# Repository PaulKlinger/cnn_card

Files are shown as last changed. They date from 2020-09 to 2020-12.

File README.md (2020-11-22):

# CNN card

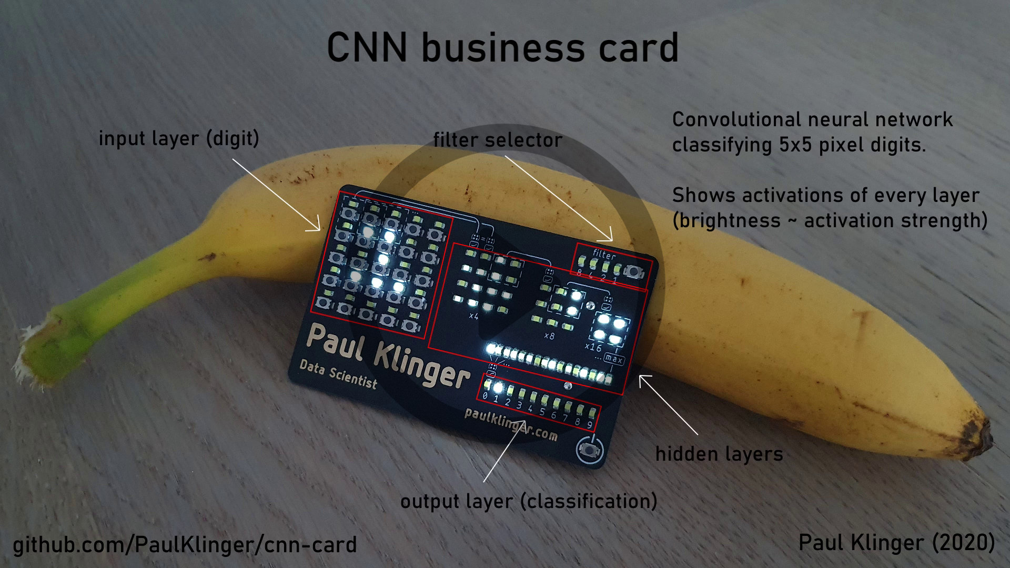
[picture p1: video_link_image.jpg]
(https://youtu.be/wtxGkK6LNEg "Project video")


Business card that runs a convolutional neural network to classify 5x5 pixel digits and shows the internal activations for all layers.

## Model
Training data / notebook for the cnn [here](https://github.com/PaulKlinger/cnn_card/blob/master/cnn).

The model consists of 3 convolutional layers (4, 8, 16 filters) and a dense layer at the output. The training data is manually generated (whatever I could come up with) + some augmentation (shifting & random pixel flips). The number of parameters is quite large compared to the number of training samples so this is probably mostly overfitting (although that might be the wrong word here, as I don't think there are many more possible samples I could have included).

## Code
The embedded code is in the [cnn_card_embedded_code.X](https://github.com/PaulKlinger/cnn_card/tree/master/cnn_card_embedded_code.X) folder (MplabX project).

The leds and buttons are driven/scanned using multiplexing, via two shift registers. The main challenge with the code was making this fast and consistent enough to allow PWM control of the brightness.

The model weights are exported to c code in [train.ipynb](https://github.com/PaulKlinger/cnn_card/blob/master/cnn/train.ipynb) and copied to [model_weights.c](https://github.com/PaulKlinger/cnn_card/blob/master/cnn_card_embedded_code.X/model_weights.c).

The aux_code directory contains some auxiliary notebooks: One to generate the startup animation (concentric pulse) and one to calculate the gamma correction table for the leds.

## Electronics
PCB design (gerbers and Eagle/Fusion sources) in the [pcb folder](https://github.com/PaulKlinger/cnn_card/tree/master/pcb).

Schematic [here](https://github.com/PaulKlinger/cnn_card/blob/master/pcb/schematic.pdf).

List of components (bill of materials) [here](https://github.com/PaulKlinger/cnn_card/blob/master/pcb/bom.csv).

I had the PCB made by elecrow.com, 1mm thickness, ENIG, matte black soldermask. I also ordered a stencil from them and used hot air & paste to solder everything (except for the battery/holder, that was done manually).

For testing I used the coin cell battery holder listed in the BOM, and then replaced it with a CR2032 with tabs soldered on (to reduce the thickness a bit).

The battery should last basically forever (decades) in standby (0.14 µA) and > 10 hours during use (it draws less than 10mA at maximum (max brightness on all leds) but probably closer to 2-3mA in normal use). After 2min of no input it automatically goes into standby mode.

I found that using white LEDs works best (in terms of max brightness), even though the forward voltage looks like it should be too high for the CR2032. At the low currents here (<0.1 mA averaged per led, <1mA momentarily due to the multiplexing) the forward voltage isn't a problem and white LEDs are just much more efficient. Also, the phosphor means that the light is more diffuse which looks nicer.

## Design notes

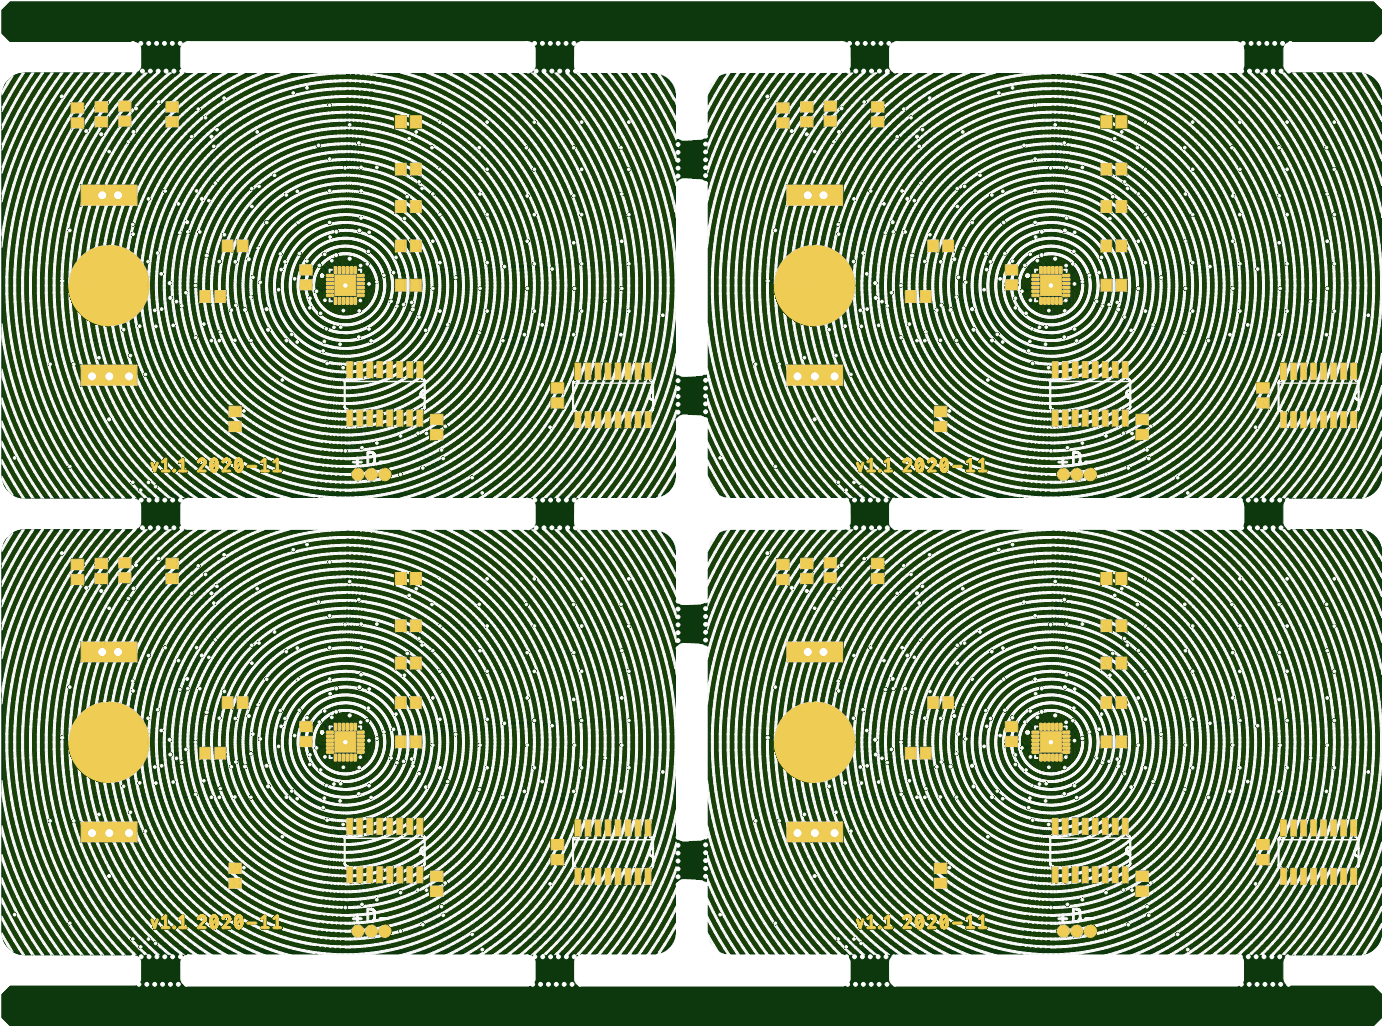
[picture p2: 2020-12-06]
pcb/panel_2x2/panel_2x2_Combined_Bottom.png

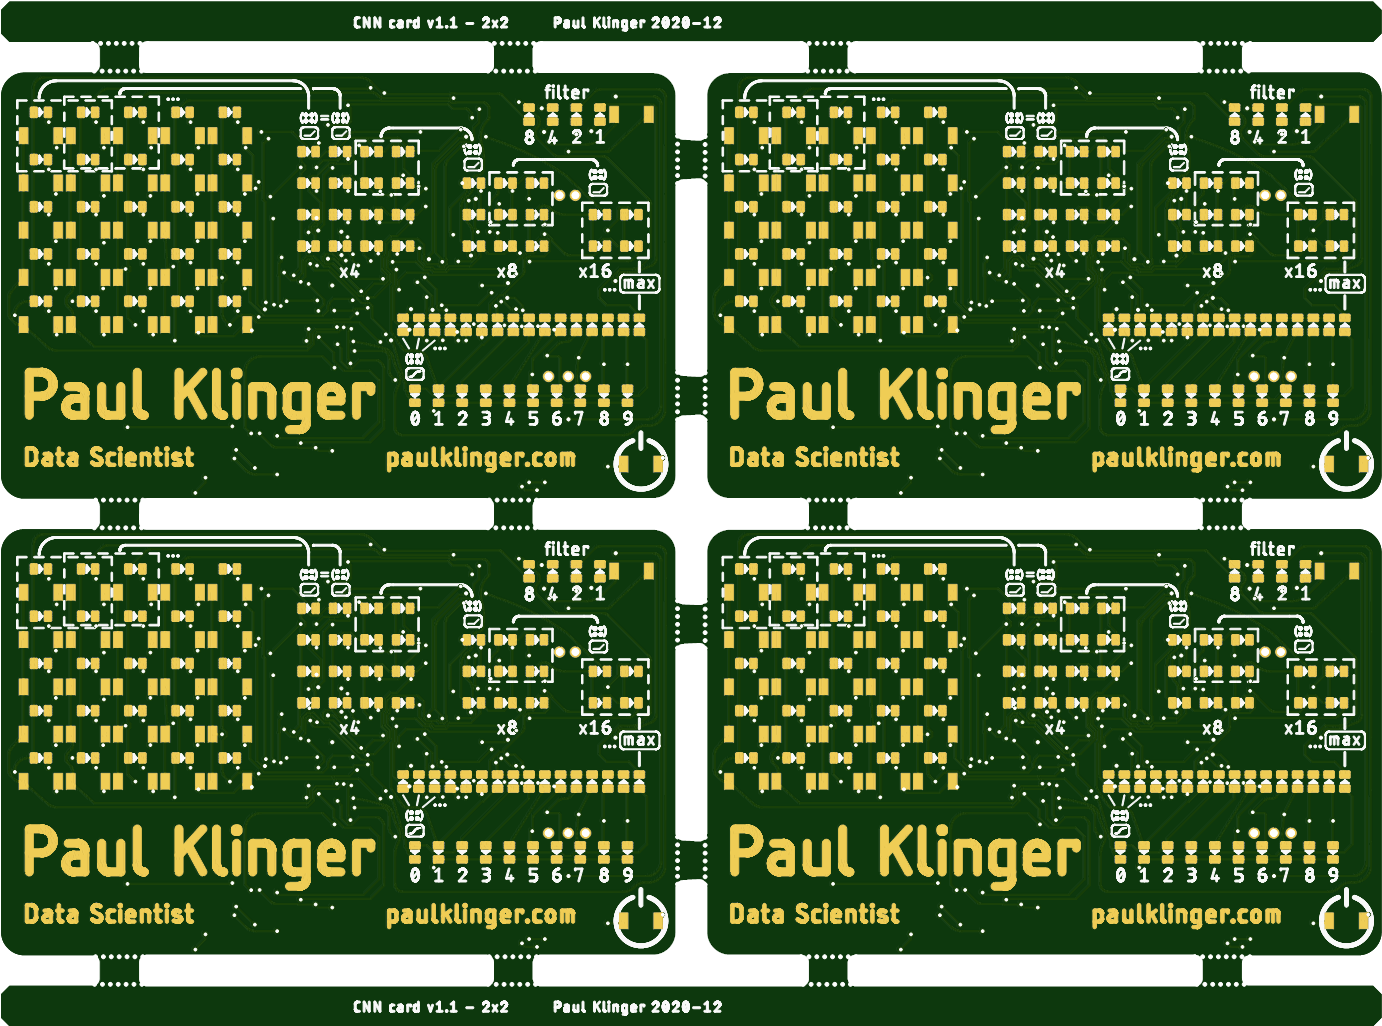
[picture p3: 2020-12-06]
pcb/panel_2x2/panel_2x2_Combined_Top.png

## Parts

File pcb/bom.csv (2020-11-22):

Qty | Value | Device | Package | Description | Parts
3 | 10uf |  | 0805 | ceramic capacitor | C1, C2, C3
9 | 220 Ω |  | 0805 | resistor | R1, R2, R3, R4, R5, R6, R7, R8, R9
3 | 2.2 kΩ |  | 0805 | resistor | R10, R11, R12
1 |  | SMTU2032-LF |  | CR2032 coin cell battery holder | U$1
2 |  | 74HC595D | SO16 | 8-bit SHIFT REGISTER, output latch | IC1, IC2
1 |  | ATTINY3217-MFR | QFN50P400X400X90-25N | Attiny3217 microcontroller | U3
27 | B3U-1000P-2P-SMD | SMD-BUTTON(2P-3.0X2.5X1.2+0.4MM)-B3U-1000P-2P-SMD | SW2-2.6-3.0X2.5X1.2+0.4MM | smd pushbutton | FILTER_SW, PWR_SW, SW1, SW2, SW3, SW4, SW5, SW6, SW7, SW8, SW9, SW10, SW11, SW12, SW13, SW14, SW15, SW16, SW17, SW18, SW19, SW20, SW21, SW22, SW23, SW24, SW25
84 |  | SMD-LED-CLEAR-WHITE(0805) | LED-0805 | white 0805 SMD led | D1, D2, D3, D4, D5, D6, D7, D8, D9, D10, D11, D12, D13, D14, D15, D16, D17, D18, D19, D20, D21, D22, D23, D24, D25, D26, D27, D28, D29, D30, D31, D32, D33, D34, D35, D36, D37, D38, D39, D40, D41, D42, D43, D44, D45, D46, D47, D48, D49, D50, D51, D52, D53, D54, D55, D56, D57, D61, D62, D63, D64, D65, D66, D67, D68, D69, D71, D72, D73, D74, D75, D76, D77, D78, D79, D81, D82, D83, D84, D85, D86, D87, D88, D89

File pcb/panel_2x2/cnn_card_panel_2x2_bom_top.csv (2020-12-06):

ID | Name | Designator | Footprint | Quantity | Manufacturer Part | Manufacturer | Supplier | Supplier Part
1 | C34499 | D34_00_00,D1_00_00,D2_00_00,D3_00_00,D4_00_00,D5_00_00,D6_00_00,D7_00_00,D8_00_00,D9_00_00,D10_00_00,D11_00_00,D12_00_00,D13_00_00,D14_00_00,D15_00_00,D16_00_00,D17_00_00,D18_00_00,D19_00_00,D20_00_00,D21_00_00,D22_00_00,D23_00_00,D24_00_00,D25_00_00,D26_00_00,D27_00_00,D28_00_00,D29_00_00,D30_00_00,D31_00_00,D32_00_00,D33_00_00,D35_00_00,D36_00_00,D37_00_00,D38_00_00,D39_00_00,D40_00_00,D41_00_00,D42_00_00,D43_00_00,D44_00_00,D45_00_00,D46_00_00,D47_00_00,D48_00_00,D49_00_00,D50_00_00,D51_00_00,D52_00_00,D53_00_00,D54_00_00,D61_00_00,D62_00_00,D63_00_00,D64_00_00,D65_00_00,D66_00_00,D67_00_00,D68_00_00,D69_00_00,D71_00_00,D72_00_00,D73_00_00,D74_00_00,D75_00_00,D76_00_00,D77_00_00,D78_00_00,D79_00_00,D81_00_00,D82_00_00,D83_00_00,D84_00_00,D85_00_00,D86_00_00,D87_00_00,D88_00_00,D89_00_00,D55_00_00,D56_00_00,D57_00_00,D34_00_01,D1_00_01,D2_00_01,D3_00_01,D4_00_01,D5_00_01,D6_00_01,D7_00_01,D8_00_01,D9_00_01,D10_00_01,D11_00_01,D12_00_01,D13_00_01,D14_00_01,D15_00_01,D16_00_01,D17_00_01,D18_00_01,D19_00_01,D20_00_01,D21_00_01,D22_00_01,D23_00_01,D24_00_01,D25_00_01,D26_00_01,D27_00_01,D28_00_01,D29_00_01,D30_00_01,D31_00_01,D32_00_01,D33_00_01,D35_00_01,D36_00_01,D37_00_01,D38_00_01,D39_00_01,D40_00_01,D41_00_01,D42_00_01,D43_00_01,D44_00_01,D45_00_01,D46_00_01,D47_00_01,D48_00_01,D49_00_01,D50_00_01,D51_00_01,D52_00_01,D53_00_01,D54_00_01,D61_00_01,D62_00_01,D63_00_01,D64_00_01,D65_00_01,D66_00_01,D67_00_01,D68_00_01,D69_00_01,D71_00_01,D72_00_01,D73_00_01,D74_00_01,D75_00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 | LED-0805 | 336 | whiteLEDSMD | KENTO | LCSC | C34499
2 | TS342A2P-WZ | SW1_00_00,SW2_00_00,SW3_00_00,SW4_00_00,SW5_00_00,SW6_00_00,SW7_00_00,SW8_00_00,SW9_00_00,SW10_00_00,SW11_00_00,SW12_00_00,SW13_00_00,SW14_00_00,SW15_00_00,SW16_00_00,SW17_00_00,SW18_00_00,SW19_00_00,SW20_00_00,SW21_00_00,SW22_00_00,SW23_00_00,SW24_00_00,SW25_00_00,PWR_SW_00_00,FILTER_SW_00_00,SW1_00_01,SW2_00_01,SW3_00_01,SW4_00_01,SW5_00_01,SW6_00_01,SW7_00_01,SW8_00_01,SW9_00_01,SW10_00_01,SW11_00_01,SW12_00_01,SW13_00_01,SW14_00_01,SW15_00_01,SW16_00_01,SW17_00_01,SW18_00_01,SW19_00_01,SW20_00_01,SW21_00_01,SW22_00_01,SW23_00_01,SW24_00_01,SW25_00_01,PWR_SW_00_01,FILTER_SW_00_01,SW1_01_00,SW2_01_00,SW3_01_00,SW4_01_00,SW5_01_00,SW6_01_00,SW7_01_00,SW8_01_00,SW9_01_00,SW10_01_00,SW11_01_00,SW12_01_00,SW13_01_00,SW14_01_00,SW15_01_00,SW16_01_00,SW17_01_00,SW18_01_00,SW19_01_00,SW20_01_00,SW21_01_00,SW22_01_00,SW23_01_00,SW24_01_00,SW25_01_00,PWR_SW_01_00,FILTER_SW_01_00,SW1_01_01,SW2_01_01,SW3_01_01,SW4_01_01,SW5_01_01,SW6_01_01,SW7_01_01,SW8_01_01,SW9_01_01,SW10_01_01,SW11_01_01,SW12_01_01,SW13_01_01,SW14_01_01,SW15_01_01,SW16_01_01,SW17_01_01,SW18_01_01,SW19_01_01,SW20_01_01,SW21_01_01,SW22_01_01,SW23_01_01,SW24_01_01,SW25_01_01,PWR_SW_01_01,FILTER_SW_01_01 | SW-SMD_L4.0-W2.9-LS5.0 | 108 | TS342A2P-WZ | SHOU HAN | LCSC | C557591

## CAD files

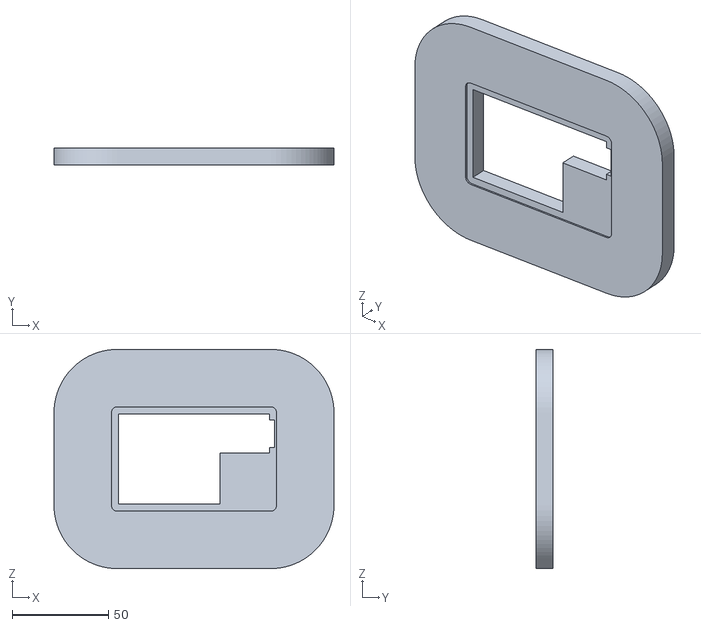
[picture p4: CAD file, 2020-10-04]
pcb/paste_holder_top.stl
145.6 x 8.90 x 114.0

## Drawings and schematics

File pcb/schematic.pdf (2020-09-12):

## VCC

1

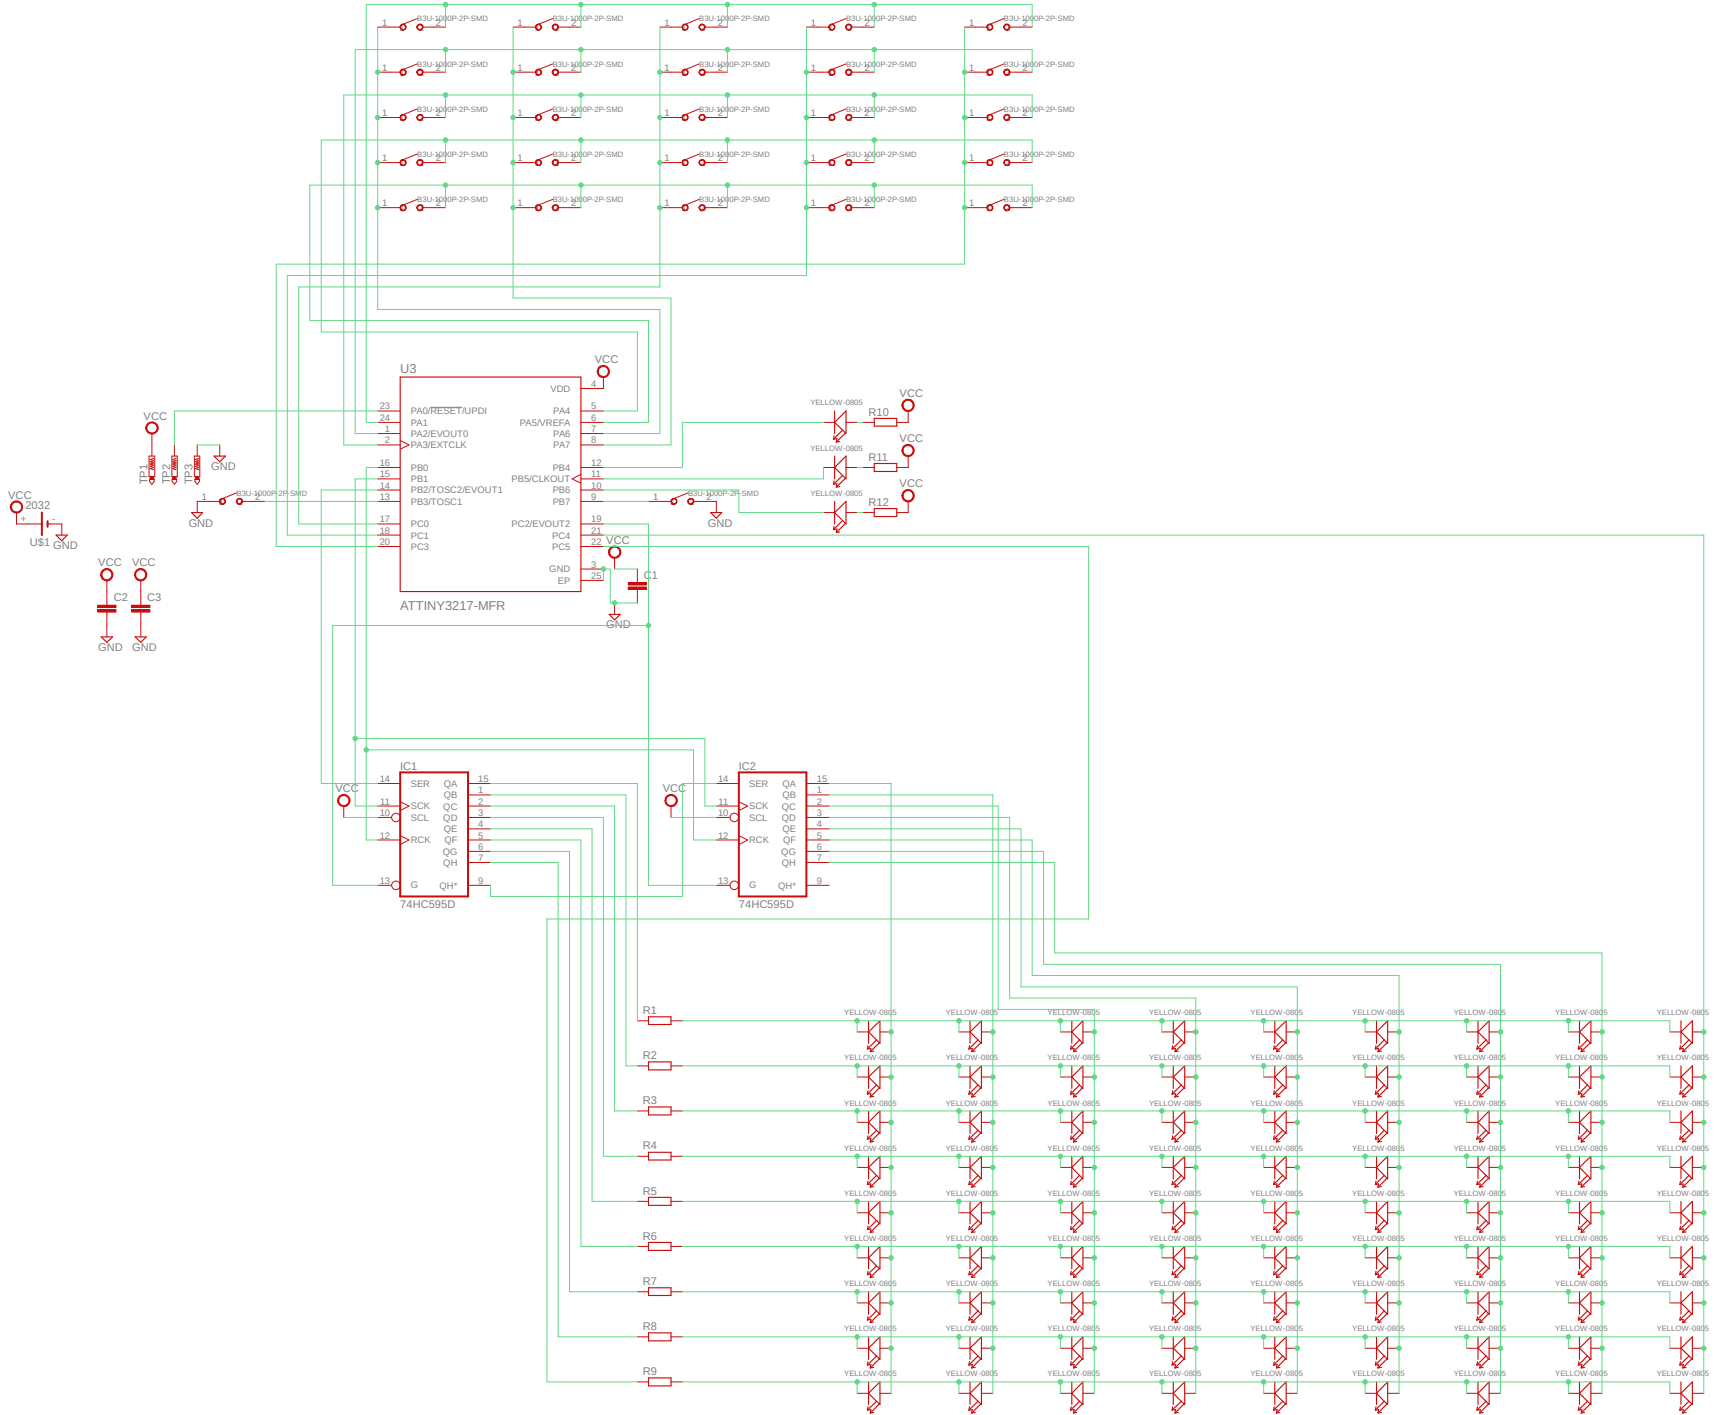
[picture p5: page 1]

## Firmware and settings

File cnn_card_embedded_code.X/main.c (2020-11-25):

#include "config.h"

#include <avr/io.h>
#include <util/delay.h>
#include <avr/sleep.h>
#include <avr/interrupt.h>

#include "model/model.h"
#include "util/led_control.h"
#include "util/buttons.h"
#include "util/sleep.h"
#include "fun/startup_anim.h"
#include "fun/gol.h"


FUSES = 
{
	.APPEND = 0,
	.BODCFG = ACTIVE_DIS_gc | LVL_BODLEVEL0_gc | SAMPFREQ_1KHZ_gc | SLEEP_DIS_gc,
	.BOOTEND = 0,
	.OSCCFG = FREQSEL_20MHZ_gc,
	.SYSCFG0 = CRCSRC_NOCRC_gc | RSTPINCFG_UPDI_gc,
	.SYSCFG1 = SUT_64MS_gc,
	.WDTCFG = PERIOD_OFF_gc | WINDOW_OFF_gc,
};


uint8_t filter_idx = 0;


ISR(PORTB_PORT_vect) {
    /* This is only used to wake the MCU, so we do nothing here. */
    /* clear interrupt flag */
    VPORTB.INTFLAGS |= PORT_INT3_bm;
}

ISR(RTC_PIT_vect)
{
    /* interrupt triggered pwm, only used when the main loop is busy */
    run_pwm_cycle();
    /* TRIGB interrupt flag has to be cleared manually */
    RTC.PITINTFLAGS = RTC_PI_bm;
}


void rtc0_init(){
    while (RTC.STATUS > 0) { /* Wait for all register to be synchronized */}
    RTC.CLKSEL = RTC_CLKSEL_INT32K_gc; /* Clock Select: Internal 32kHz OSC */
    
    /* 10 min period 
     * (should never reach this, as we reset on auto shutdown at <10 min)
     */
    RTC.PER = 60 * 10; 
    RTC.CTRLA = RTC_PRESCALER_DIV32768_gc/* Prescaling Factor: RTC Clock / 32768 */
                | 1 << RTC_RTCEN_bp /* Enable: enabled */
                | 0 << RTC_RUNSTDBY_bp; /* Run In Standby: disabled */
    
    while (RTC.PITSTATUS > 0) {}
    /* set PIT period (for PWM during calculations) but don't enable it
     * most of the time we'll just run PWM in main loop so it's faster.
     */
    RTC.PITINTCTRL = RTC_PI_bm;
    RTC.PITCTRLA = RTC_PERIOD_CYC512_gc; // = 64 Hz

}


void usart_spi_init(){
    PORTB.PIN0CTRL |= PORT_INVEN_bm;
    USART0.CTRLA = USART_RS4850_bm;
    USART0.CTRLB |= USART_TXEN_bm; /* enable TX (but not RX) */
    
    /* change mode to master SPI */
    USART0.CTRLC = USART_CMODE_MSPI_gc ; 
    
    /* set baud factor to 1 -> f_baud = 2MHz for CLK_PER = 4MHz*/
    USART0.BAUDL = (1 << 6);
}


void run_model_with_pwm() {
    // enable interrupt pwm during model calculations
    RTC.PITCTRLA |= RTC_PITEN_bm;

    run_model_and_set_led_brightness(filter_idx);

    // disable interrupt pwm again
    RTC.PITCTRLA &= ~RTC_PITEN_bm;
}


void reset_input_state() {
    filter_idx = 0;
    clear_led_brightness();
    set_led_brightness(1, 1, MAX_PWM_LEVEL);
    set_led_brightness(1, 2, MAX_PWM_LEVEL);
    set_led_brightness(2, 2, MAX_PWM_LEVEL);
    set_led_brightness(3, 1, MAX_PWM_LEVEL);
    set_led_brightness(3, 2, MAX_PWM_LEVEL);
    set_led_brightness(3, 3, MAX_PWM_LEVEL);
    
    set_filter_leds(filter_idx);
    update_pwm_pattern();
    
    run_model_with_pwm();
    update_pwm_pattern();
}


void sleep_and_reset() {
    turn_off_leds();
    go_to_sleep();
    run_startup_animation();
    reset_input_state();
}


void handle_buttons(){
    int8_t pressed = read_buttons();
    if (pressed == -1) {
        return;
    } else if (pressed == FILTER_BUTTON) {
        if (check_glider()) {
            run_gol();
        } else {
            filter_idx = (filter_idx + 1) % N_FILTERS;
        }
        run_model_with_pwm();
        set_filter_leds(filter_idx);
        update_pwm_pattern();
    } else if (pressed == PWR_BUTTON) {
        sleep_and_reset();
    } else {
        uint8_t row = pressed / 5;
        uint8_t col = pressed % 5;

        set_led_brightness(row, col,
            get_led_on(row, col) ? 0 : MAX_PWM_LEVEL
        );

        run_model_with_pwm();
        update_pwm_pattern();
    }
}


void main_loop() {
    
    while (1) {
        run_pwm_cycle();
        handle_buttons();
        if (RTC.CNT > AUTO_SHUTDOWN_TIME_s) {
            sleep_and_reset();
        }
    }
}


int main(void) {
      /* Configure clock prescaler for 4MHz  */
    _PROTECTED_WRITE(
            CLKCTRL.MCLKCTRLB,
            CLKCTRL_PDIV_2X_gc /* Prescaler division: 2X */
            | CLKCTRL_PEN_bm /* Prescaler enable: enabled */
            );
    
    /* Enable pullups for low power consumption (20uA -> 0.1uA (afair))*/
    PORTA.PIN0CTRL |= PORT_PULLUPEN_bm;
    PORTA.PIN1CTRL |= PORT_PULLUPEN_bm;
    PORTA.PIN2CTRL |= PORT_PULLUPEN_bm;
    PORTA.PIN3CTRL |= PORT_PULLUPEN_bm;
    PORTA.PIN4CTRL |= PORT_PULLUPEN_bm;
    PORTA.PIN5CTRL |= PORT_PULLUPEN_bm;
    PORTA.PIN6CTRL |= PORT_PULLUPEN_bm;
    PORTA.PIN7CTRL |= PORT_PULLUPEN_bm;
    
    PORTB.PIN0CTRL |= PORT_PULLUPEN_bm;
    PORTB.PIN1CTRL |= PORT_PULLUPEN_bm;
    PORTB.PIN2CTRL |= PORT_PULLUPEN_bm;
    PORTB.PIN3CTRL |= PORT_PULLUPEN_bm;
    PORTB.PIN4CTRL |= PORT_PULLUPEN_bm;
    PORTB.PIN5CTRL |= PORT_PULLUPEN_bm;
    PORTB.PIN6CTRL |= PORT_PULLUPEN_bm;
    PORTB.PIN7CTRL |= PORT_PULLUPEN_bm;
    
    
    PORTC.PIN0CTRL |= PORT_PULLUPEN_bm;
    PORTC.PIN1CTRL |= PORT_PULLUPEN_bm;
    PORTC.PIN2CTRL |= PORT_PULLUPEN_bm;
    PORTC.PIN3CTRL |= PORT_PULLUPEN_bm;
    PORTC.PIN4CTRL |= PORT_PULLUPEN_bm;
    PORTC.PIN5CTRL |= PORT_PULLUPEN_bm;
    PORTC.PIN6CTRL |= PORT_PULLUPEN_bm;
    PORTC.PIN7CTRL |= PORT_PULLUPEN_bm;
    
    
    /* Enable interrupt on power button
     * (this is only for wakeup)*/
    PORTB.PIN3CTRL = (PORTB.PIN3CTRL & ~PORT_ISC_gm) | PORT_ISC_BOTHEDGES_gc;
    sei();
    
    rtc0_init();
    
    usart_spi_init();
    
    // shift register output disable
    VPORTC.OUT |= PIN2_bm;
    // GPIO led row/col off
    VPORTC.OUT &= ~PIN4_bm;
    VPORTC.OUT |= PIN5_bm;
    
    // turn off individual leds
    VPORTB.OUT |= (PIN4_bm | PIN5_bm | PIN6_bm);
    
    VPORTB.DIR = (PIN0_bm | PIN1_bm | PIN2_bm | PIN4_bm | PIN5_bm | PIN6_bm);
    VPORTC.DIR |= (PIN2_bm | PIN4_bm | PIN5_bm);
    

    
    
    turn_off_leds();
    
    /* shift register output enable */
    VPORTC.OUT &= ~PIN2_bm;
    
    init_pwm_data();
    
    // sleep
    sleep_and_reset();
    
    main_loop();
    
}

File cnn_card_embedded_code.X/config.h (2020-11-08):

/* 
 * File:   config.h
 * Author: kling
 *
 * Created on 27 September 2020, 17:59
 */

#ifndef CONFIG_H
#define	CONFIG_H

#ifdef	__cplusplus
extern "C" {
#endif
    
#define F_CPU 10000000

// config options
#define DEBOUNCE_THRESHOLD 5
#define AUTO_SHUTDOWN_TIME_s 60 * 2 // 2 min

#define LED_COUNT 5 * 5 + 4 * 4 + 3 * 3 + 2 * 2 + 16 + 10 + 4
#define PWM_BITS 6 /* NEED TO CHANGE gamma_table in led_status.c if this changes! */
#define N_FILTERS 16

    
#define PWM_LEVELS (1 << PWM_BITS)
#define MAX_PWM_LEVEL (PWM_LEVELS - 1)


#ifdef	__cplusplus
}
#endif

#endif	/* CONFIG_H */

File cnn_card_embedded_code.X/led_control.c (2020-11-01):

#include "led_control.h"
#include "config.h"
#include <stdint.h>
#include <avr/io.h>
#include <util/delay.h>
#include <stdbool.h>


/* PWM_BITS-bit brightness values for each led*/
uint8_t led_status[LED_STATUS_BYTES] = {0};


/* precomputed bytes to shift out during main loop*/
uint8_t row_shift_bytes[PWM_LEVELS * 9];
uint8_t col_shift_bytes[9];

/* brightness of row8 leds (not controlled via shift register) */
uint8_t row8_brightness[9];


/* gamma correction table
 * led_value ∈ [0,1)= (perceived brightness ∈ [0,1))^2.8 */
const uint8_t gamma_table[] = {
  0,0,0,0,0,0,0,0,0,0,0,0,0,0,0,
  0,0,0,0,0,0,0,0,1,1,1,1,1,1,1,
  1,1,1,1,2,2,2,2,2,2,2,3,3,3,3,
  3,4,4,4,4,5,5,5,5,6,6,6,7,7,7,
  8,8,8,9,9,9,10,10,11,11,12,12,13,13,14,
  14,15,15,16,16,17,17,18,19,19,20,21,21,22,23,
  23,24,25,26,27,27,28,29,30,31,32,32,33,34,35,
  36,37,38,39,40,41,42,43,44,46,47,48,49,50,51,
  53,54,55,56,58,59,60,62,63 };


uint8_t value_to_pwm_level(float value, float max_value) {
    /* convert float value in [0, max_value] to pwm level */
    return gamma_table[(uint8_t) (value / max_value * 128)];
}


void clear_led_brightness() {
    for (uint16_t i=0; i < sizeof(led_status); i++) {
        led_status[i] = 0;
    }
}


uint8_t get_led_brightness(uint8_t row, uint8_t col) {
    uint16_t start_idx = (row * 9 + col) * PWM_BITS;
    uint8_t out = 0;
    
    for (uint8_t i=0; i < PWM_BITS; i++) {
        out += (!!(led_status[(start_idx + i) / 8] & (1 << ((start_idx + i) % 8)))) << i;
    }
    
    return out;
}

bool get_led_on(uint8_t row, uint8_t col) {
    uint16_t start_idx = (row * 9 + col) * PWM_BITS;
    return led_status[(start_idx) / 8] & (1 << (start_idx % 8));
}


void set_led_brightness(uint8_t row, uint8_t col, uint8_t val) {
    uint16_t start_idx = (row * 9 + col) * PWM_BITS;
    for (uint8_t i = 0; i < PWM_BITS; i++){
        if (val & (1 << i)) {
            led_status[(start_idx + i) / 8] |= (1 << ((start_idx + i) % 8));
        } else {
            led_status[(start_idx + i) / 8] &= ~(1 << ((start_idx + i) % 8));
        }
    }
}


void init_pwm_data() {
    // set column select shift pattern for first 8 cols
    // don't compute this dynamically to make pwm cycles more even
    for (uint8_t col=0; col < 8; col++) {
        col_shift_bytes[col] = (1 << col);
    }
    col_shift_bytes[8] = 0;
}


void update_pwm_pattern() {
    for (uint8_t row=0; row <= 8; row++) {
        for (uint8_t col=0; col <= 8; col++) {
            uint8_t brightness = get_led_brightness(row, col);
            if (row == 8) {
                row8_brightness[col] = brightness;
            } else {
                for (uint8_t pwm_index=0; pwm_index < PWM_LEVELS; pwm_index++) {
                    if (pwm_index < brightness) {
                        row_shift_bytes[9 * pwm_index + col] &= ~(1 << (row % 8));
                    } else {
                        row_shift_bytes[9 * pwm_index + col] |= (1 << (row % 8));
                    }
                }
            }
        }
    }
}


void turn_off_leds() {
    /* shift out pattern for all leds off*/
    /* wait for tx buffer ready*/
    while (!(USART0.STATUS & USART_DREIF_bm)){}
    USART0.TXDATAL = 0;
    while (!(USART0.STATUS & USART_DREIF_bm)){}
    USART0.TXDATAL = 255;
    
    /* turn off GPIO controlled row/col 8 */
    VPORTC.OUT |= PIN5_bm;
    VPORTC.OUT &= ~PIN4_bm;
    
    /* turn off individual leds 
     * (change to input to remember value) */
    VPORTB.DIR &= ~(PIN4_bm | PIN5_bm | PIN6_bm);
}


void run_pwm_cycle() {
    /* Run a full PWM cycle: PWM_LEVELS * 9 columns different output states */
    
    // turn on single leds
    VPORTB.DIR |= (PIN4_bm | PIN5_bm | PIN6_bm);
    uint8_t set_vportc = VPORTC.OUT;
    uint8_t next_vportc = VPORTC.OUT;
    for (uint8_t pwm_idx=0; pwm_idx < PWM_LEVELS; pwm_idx++) {
        for (uint8_t col=0; col <= 8; col++){
            /* set column */
            if (col == 8) {
                next_vportc = VPORTC.OUT | PIN4_bm;
            } else {
                next_vportc = VPORTC.OUT & ~PIN4_bm;
            }

           /* set row8 */
            if (pwm_idx < row8_brightness[col]) {
                next_vportc &= ~PIN5_bm;
            } else {
                next_vportc |= PIN5_bm;
            }

            /* shift register output disable */
            VPORTC.OUT |= PIN2_bm;
            /* turn off row8, this ensures that led (8,8) isn't brighter
             * (it would be on during the wait loop below) */
            VPORTC.OUT |= PIN5_bm;

            /* wait for shift out to complete 
             * (RCK will be pulsed automatically) */
            /* TODO: replacing this with _delay_us(1) improves speed
             * significantly, but then col 7 is active longer */
            while (!(USART0.STATUS & USART_TXCIF_bm)) {}

            // need to clear transmit complete flag manually
            USART0.STATUS |= USART_TXCIF_bm;

            /* set col8 / row8 and enable shift register output */
            VPORTC.OUT = set_vportc;


            USART0.TXDATAL = col_shift_bytes[col];
            while (!(USART0.STATUS & USART_DREIF_bm)){}
            USART0.TXDATAL = row_shift_bytes[9 * pwm_idx + col];

            set_vportc = next_vportc;
        }
    }
    // pulse SCK & set portc for last iteration  
    _delay_us(4);
    VPORTC.OUT = set_vportc;
    _delay_us(8);
    // turn off leds (otherwise last col is brighter
    // because of button scan time)
    turn_off_leds();
}

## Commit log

2020-09-12 PCB cam file & gerbers
    [cnn_card.GBL, cnn_card.GBO, cnn_card.GBP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]
2020-09-12 added pdf schematic
2020-09-12 initial commit of code, just some experiments with sleep mode, USART SPI, etc.
2020-09-15 added led test function - all LEDs working :D
2020-09-18 button reading (with debouncing)
2020-09-19 test pwm dimming (just global for testing)
2020-09-20 power off on reset, auto power off, cleanup
    [main.c]
2020-09-21 per-led brightness, precalculated shift row bytes
2020-09-21 made pwm bit depth configurable
2020-09-22 optimised PWM loop
2020-09-22 bugfix for row8 data, got rid of "1 << pwm_index" in loop (now pwm is uniform :D)
    turns out 1 << 31 actually takes 31 operations on avr...
    [main.c]
2020-09-23 cleanup, made filter button cycle through
2020-09-26 3d printed pcb holder for pasting / placing
    [paste_holder_top.stl]
2020-09-27 reorganisation, working output layer leds
2020-09-27 set led brightness for intermediate layers
2020-09-28 added gamma correction, increased PWM bit depth
    [config.h, model.c]
2020-10-03 moved pwm cycle out of main.c
2020-10-03 added periodic interrupt triggered pwm cycles during model calculation (to prevent LEDs going completely dark)
    [main.c]
2020-10-04 added startup animation, reset on wake
    [led_control.c, main.c, startup_anim.c]
2020-10-04 ensure filter leds are off on startup
2020-10-04 fixed pcb holder cutout
    [paste_holder_top.stl]
2020-11-22 added bom
    [bom.csv]
2020-11-22 fixed led color in bom
    [bom.csv]
2020-11-22 check/update shutdown timer during gol
2020-11-22 updated bom link in readme
2020-11-22 added schematic link
2020-11-25 rtc counter is reset in read_buttons(), don't reset it again
    [gol.c]
2020-12-06 added gerbers for 2x2 panel
    [cnn_card_panel_2x2_bom_top.csv, cnn_card_panel_2x2_pnp_top.csv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]
2020-12-06 Added code to panelize bom & pnp files
2020-12-06 added gerberset file (gerbertools panelizer) for 2x2 panel
2020-12-06 update pcb files: cr2032 clip, bigger pads for switches,...
    [cnn_card.GBL, cnn_card.GBO, cnn_card.GBP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]
